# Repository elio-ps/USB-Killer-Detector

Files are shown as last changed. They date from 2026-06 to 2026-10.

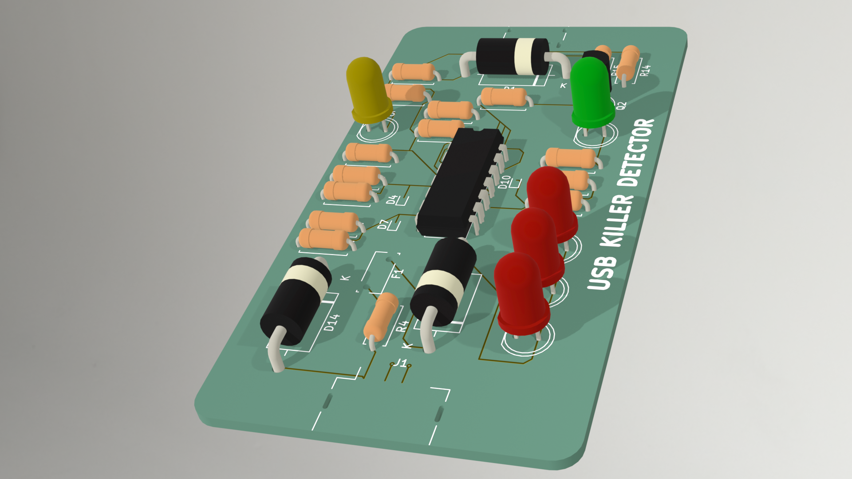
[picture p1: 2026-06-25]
PCB/rednue.png

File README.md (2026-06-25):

# USB Killer Detector

> An open-source tool for detecting, monitoring, and analyzing potentially dangerous USB devices before they can harm your system.

## License

This project is licensed under the GNU GPL v3.0.
See the LICENSE file for more information.

## Overview

USB Killer Detector is an open-source security tool designed to help users identify and inspect USB devices connected to their systems. The project aims to improve hardware security awareness and provide useful information about connected peripherals through real-time monitoring and analysis.

## Demo Video

<p align="center">
  Demo
</p>

*Click the image to watch the demonstration video.*

## Features

* Real-time USB device detection
* Device information gathering and analysis
* Event logging and monitoring
* Detection of suspicious USB behaviors
* Lightweight and efficient design
* Open-source and community-driven
* Easy integration into security workflows

## Why This Project?

Malicious USB devices can pose serious risks to computers and embedded systems. USB * Evan Siby
Killer Detector provides visibility into connected hardware, helping users better understand what devices are attached to their systems and identify potentially dangerous behavior.

## Installation

```bash
git clone https://github.com/elio-ps/USB-Killer-Detector.git
cd USB-Killer-Detector
```

## Architecture

The project is built around several core components:

* USB device monitoring
* Device information collection
* Analysis engine
* Event logging system
* User interface and reporting

## Contributing

Contributions are welcome.

1. Fork the repository
2. Create a feature branch
3. Commit your changes
4. Open a Pull Request

## Acknowledgments

Thanks to all contributors, testers, and members of the open-source community who help improve this project :
* Philippe Mege
* Lenny Gaillard
* Evan Siby
* Lucas Rios

## About Us

We are currently beginners in electronics and embedded systems. This project is mainly a learning experience where we explore USB devices, hardware behavior, and basic security concepts.

We’re improving step by step, so any advice, ideas, or contributions are very welcome!

## Support

If you find this project useful, consider giving it a ⭐ on GitHub and sharing your feedback.

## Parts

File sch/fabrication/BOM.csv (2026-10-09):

Repere | Valeur | Empreinte | Reference fabricant | Quantite
C1 | 10uF | Capacitor_SMD:C_0805_2012Metric |  | 1
C2,C3,C4,C8,C9,C10 | 100nF | Capacitor_SMD:C_0805_2012Metric |  | 6
C5,C6,C7 | 1nF | Capacitor_SMD:C_0805_2012Metric |  | 3
C11 | 1uF | Capacitor_SMD:C_0805_2012Metric |  | 1
D1,D4 | SMAJ5.0A | Diode_SMD:D_SMA | SMAJ5.0A | 2
D2 | Orange PWR | LED_THT:LED_D5.0mm |  | 1
D3 | SS34 | Diode_SMD:D_SMA | SS34 | 1
D5,D6,D7 | BAT54S | Package_TO_SOT_SMD:SOT-23 | BAT54S | 3
D8,D12,D13,D14 | 1N4148W | Diode_SMD:D_SOD-123 | 1N4148W | 4
D9 | Rouge D+ | LED_THT:LED_D5.0mm |  | 1
D10 | Rouge D- | LED_THT:LED_D5.0mm |  | 1
D11 | Rouge VBUS | LED_THT:LED_D5.0mm |  | 1
D15 | Verte OK | LED_THT:LED_D5.0mm |  | 1
F1 | 500mA hold | Fuse:Fuse_1812_4532Metric | Bourns MF-MSMF050-2 | 1
J1 | USB-A test | Connector_USB:USB_A_Receptacle_GCT_USB1046 | GCT USB1046 | 1
J2 | USB-C alim | Connector_USB:USB_C_Receptacle_GCT_USB4125-xx-x_6P_TopMnt_Horizontal | GCT USB4125-GF-A | 1
R1,R2 | 5.1k | Resistor_SMD:R_0805_2012Metric |  | 2
R3,R22,R23,R24,R26 | 1k | Resistor_SMD:R_0805_2012Metric |  | 5
R4 | 51k | Resistor_SMD:R_0805_2012Metric |  | 1
R5 | 33k | Resistor_SMD:R_0805_2012Metric |  | 1
R6 | 15k | Resistor_SMD:R_0805_2012Metric |  | 1
R7,R8,R11,R12 | 220k | Resistor_SMD:R_1206_3216Metric |  | 4
R9,R13 | 220k | Resistor_SMD:R_0805_2012Metric |  | 2
R10,R14 | 120k | Resistor_SMD:R_0805_2012Metric |  | 2
R15 | 100k | Resistor_SMD:R_1206_3216Metric |  | 1
R16 | 150k | Resistor_SMD:R_0805_2012Metric |  | 1
R17 | 43k | Resistor_SMD:R_0805_2012Metric |  | 1
R18,R19,R20 | 10k | Resistor_SMD:R_0805_2012Metric |  | 3
R21,R25 | 100k | Resistor_SMD:R_0805_2012Metric |  | 2
SW1 | RESET | Button_Switch_SMD:SW_SPST_B3S-1000 | Omron B3S-1000 | 1
U1,U2 | LM339 | Package_SO:SOIC-14_3.9x8.7mm_P1.27mm | LM339DR | 2
U3 | 74HC279 | Package_SO:SOIC-16_3.9x9.9mm_P1.27mm | 74HC279D | 1

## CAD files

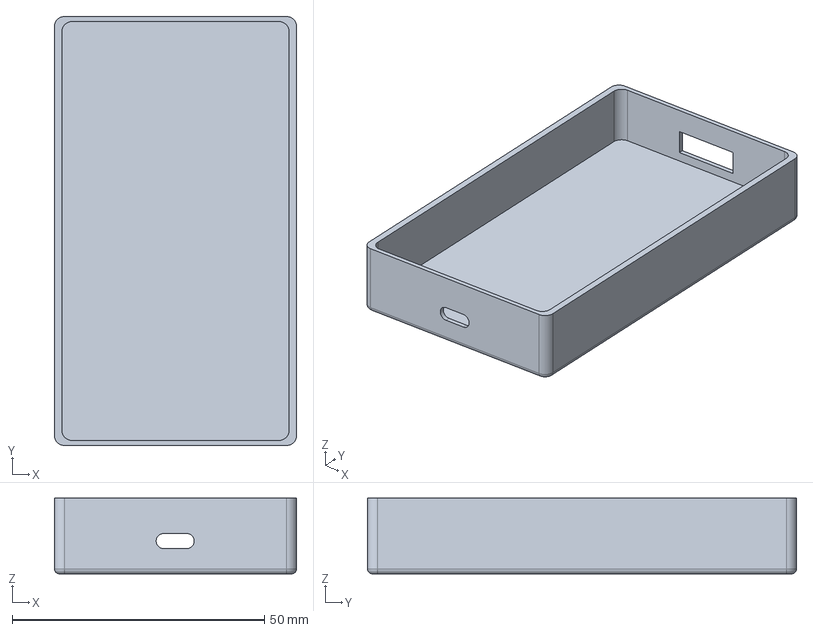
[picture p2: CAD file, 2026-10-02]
PCB/Case/Case.FCStd
48.0 x 85.0 x 15.0 mm

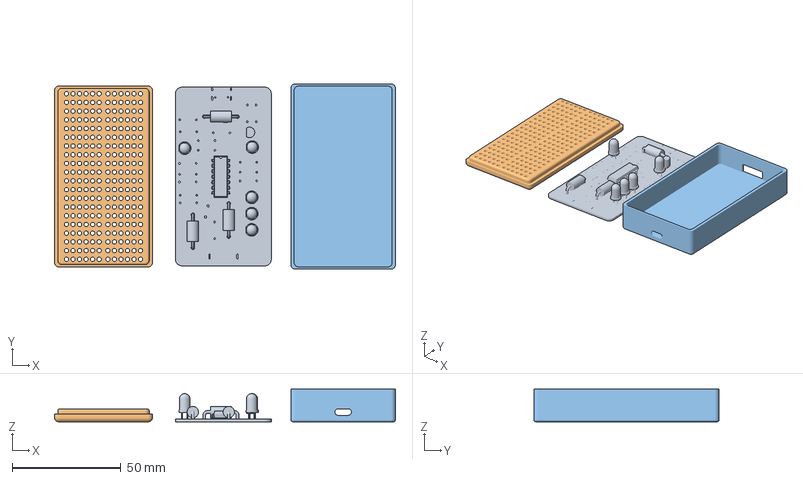
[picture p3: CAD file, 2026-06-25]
PCB/Model.3mf
156.5 x 85.0 x 15.0 mm
a
couvercle-Body
boitier-Body

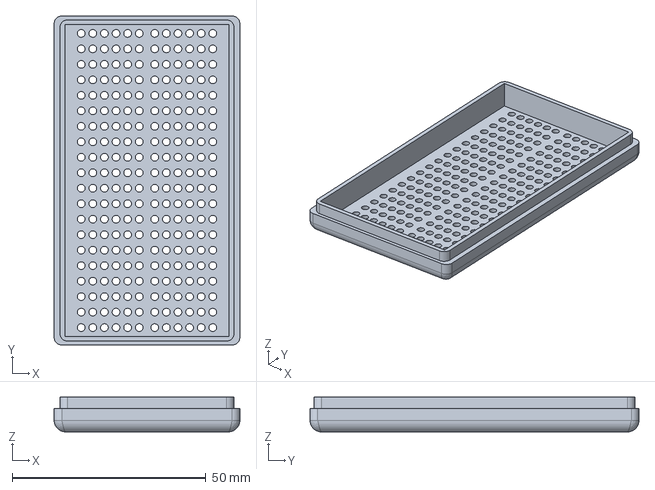
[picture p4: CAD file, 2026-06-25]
PCB/Case/Lid.FCStd
48.0 x 85.0 x 9.00 mm

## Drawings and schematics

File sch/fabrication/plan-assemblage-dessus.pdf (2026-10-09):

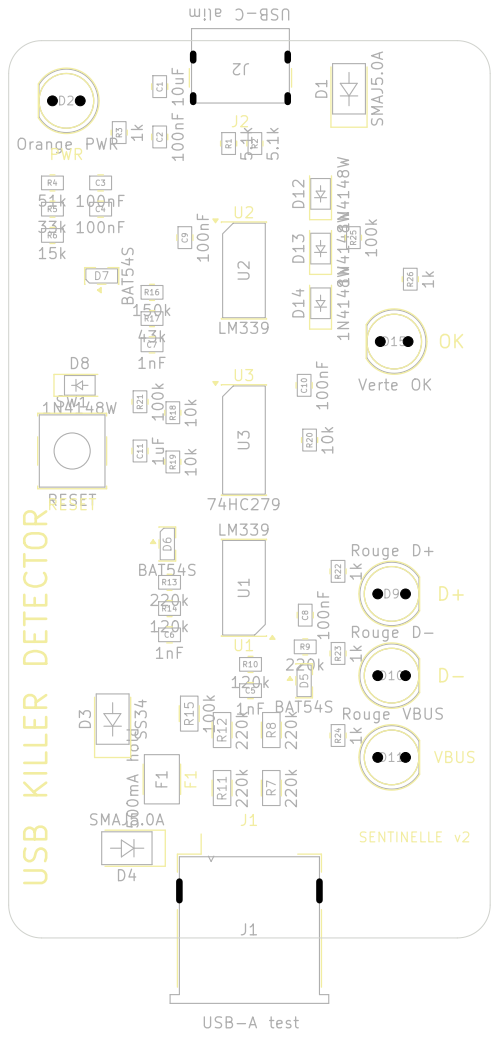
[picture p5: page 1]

File: usb-killer-detector.kicad_pcb
Title:

Size: A4 | Rev:
KiCad E.D.A. 10.0.3 | Id: 1/1

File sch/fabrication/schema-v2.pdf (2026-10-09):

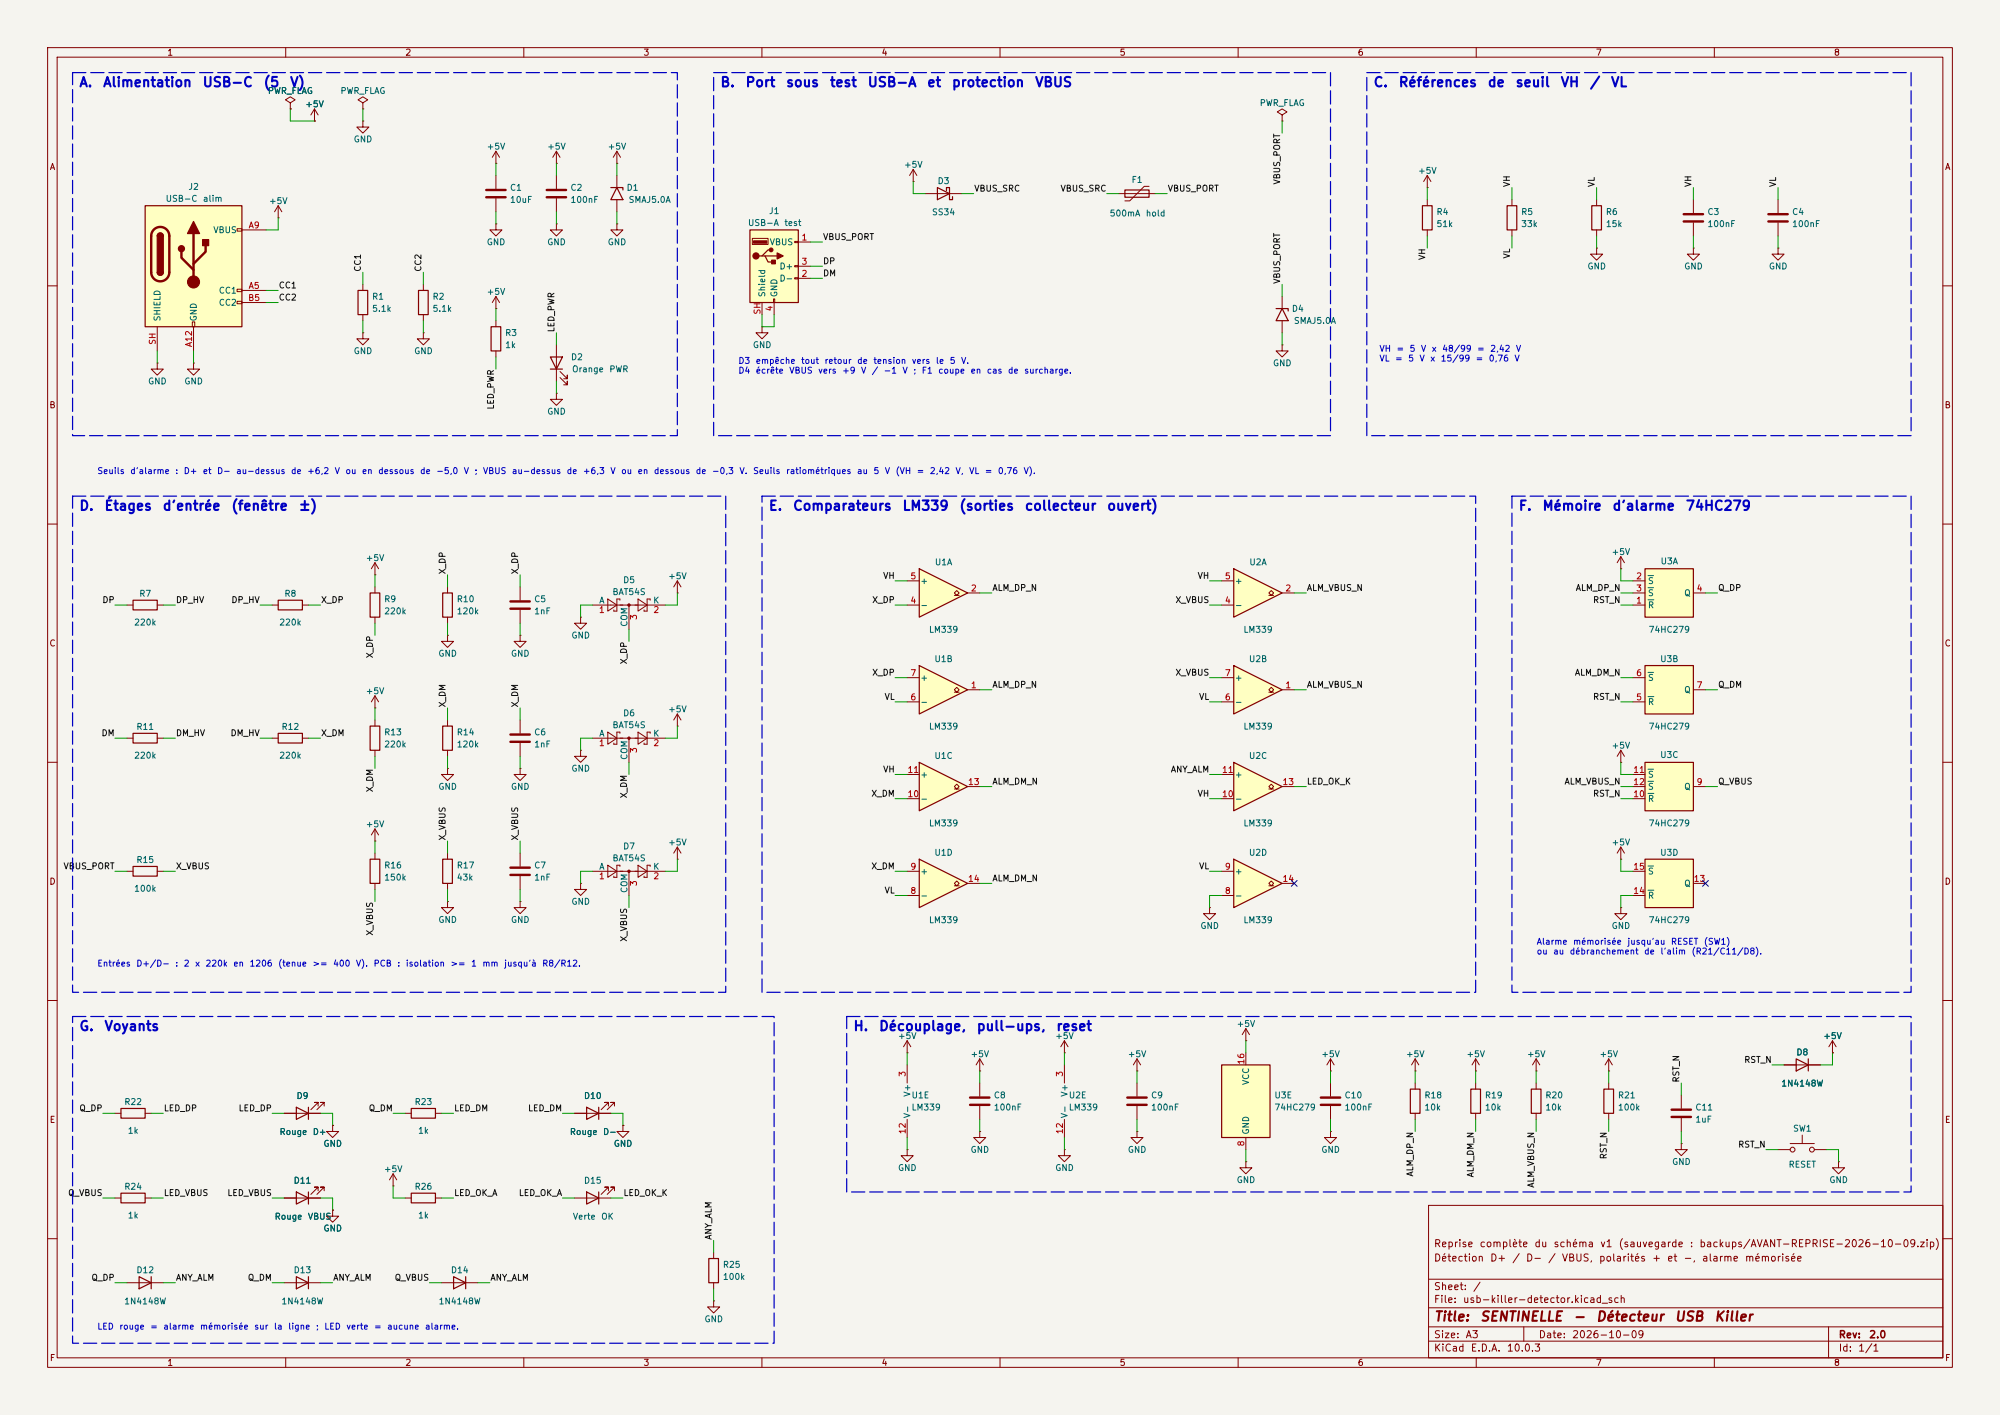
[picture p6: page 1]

VL = 5 V x 15/99 = 0,76 V C. Références de seuil VH / VL

D3 empêche tout retour de tension vers le 5 V. D4 écrête VBUS vers +9 V / -1 V ; F1 coupe en cas de surcharge.

LED rouge = alarme mémorisée sur la ligne ; LED verte = aucune alarme. Entrées D+/D- : 2 x 220k en 1206 (tenue >= 400 V). PCB : isolation >= 1 mm jusqu'à R8/R12.

H. Découplage, pull-ups, reset

Reprise complète du schéma v1 (sauvegarde : backups/AVANT-REPRISE-2026-10-09.zip)
Détection D+ / D- / VBUS, polarités + et -, alarme mémorisée

Sheet: /
File: usb-killer-detector.kicad_sch
Title: SENTINELLE - Détecteur USB Killer

Size: A3 | Rev: 2.0
KiCad E.D.A. 10.0.3 | Id: 1/1 | F Date: 2026-10-09

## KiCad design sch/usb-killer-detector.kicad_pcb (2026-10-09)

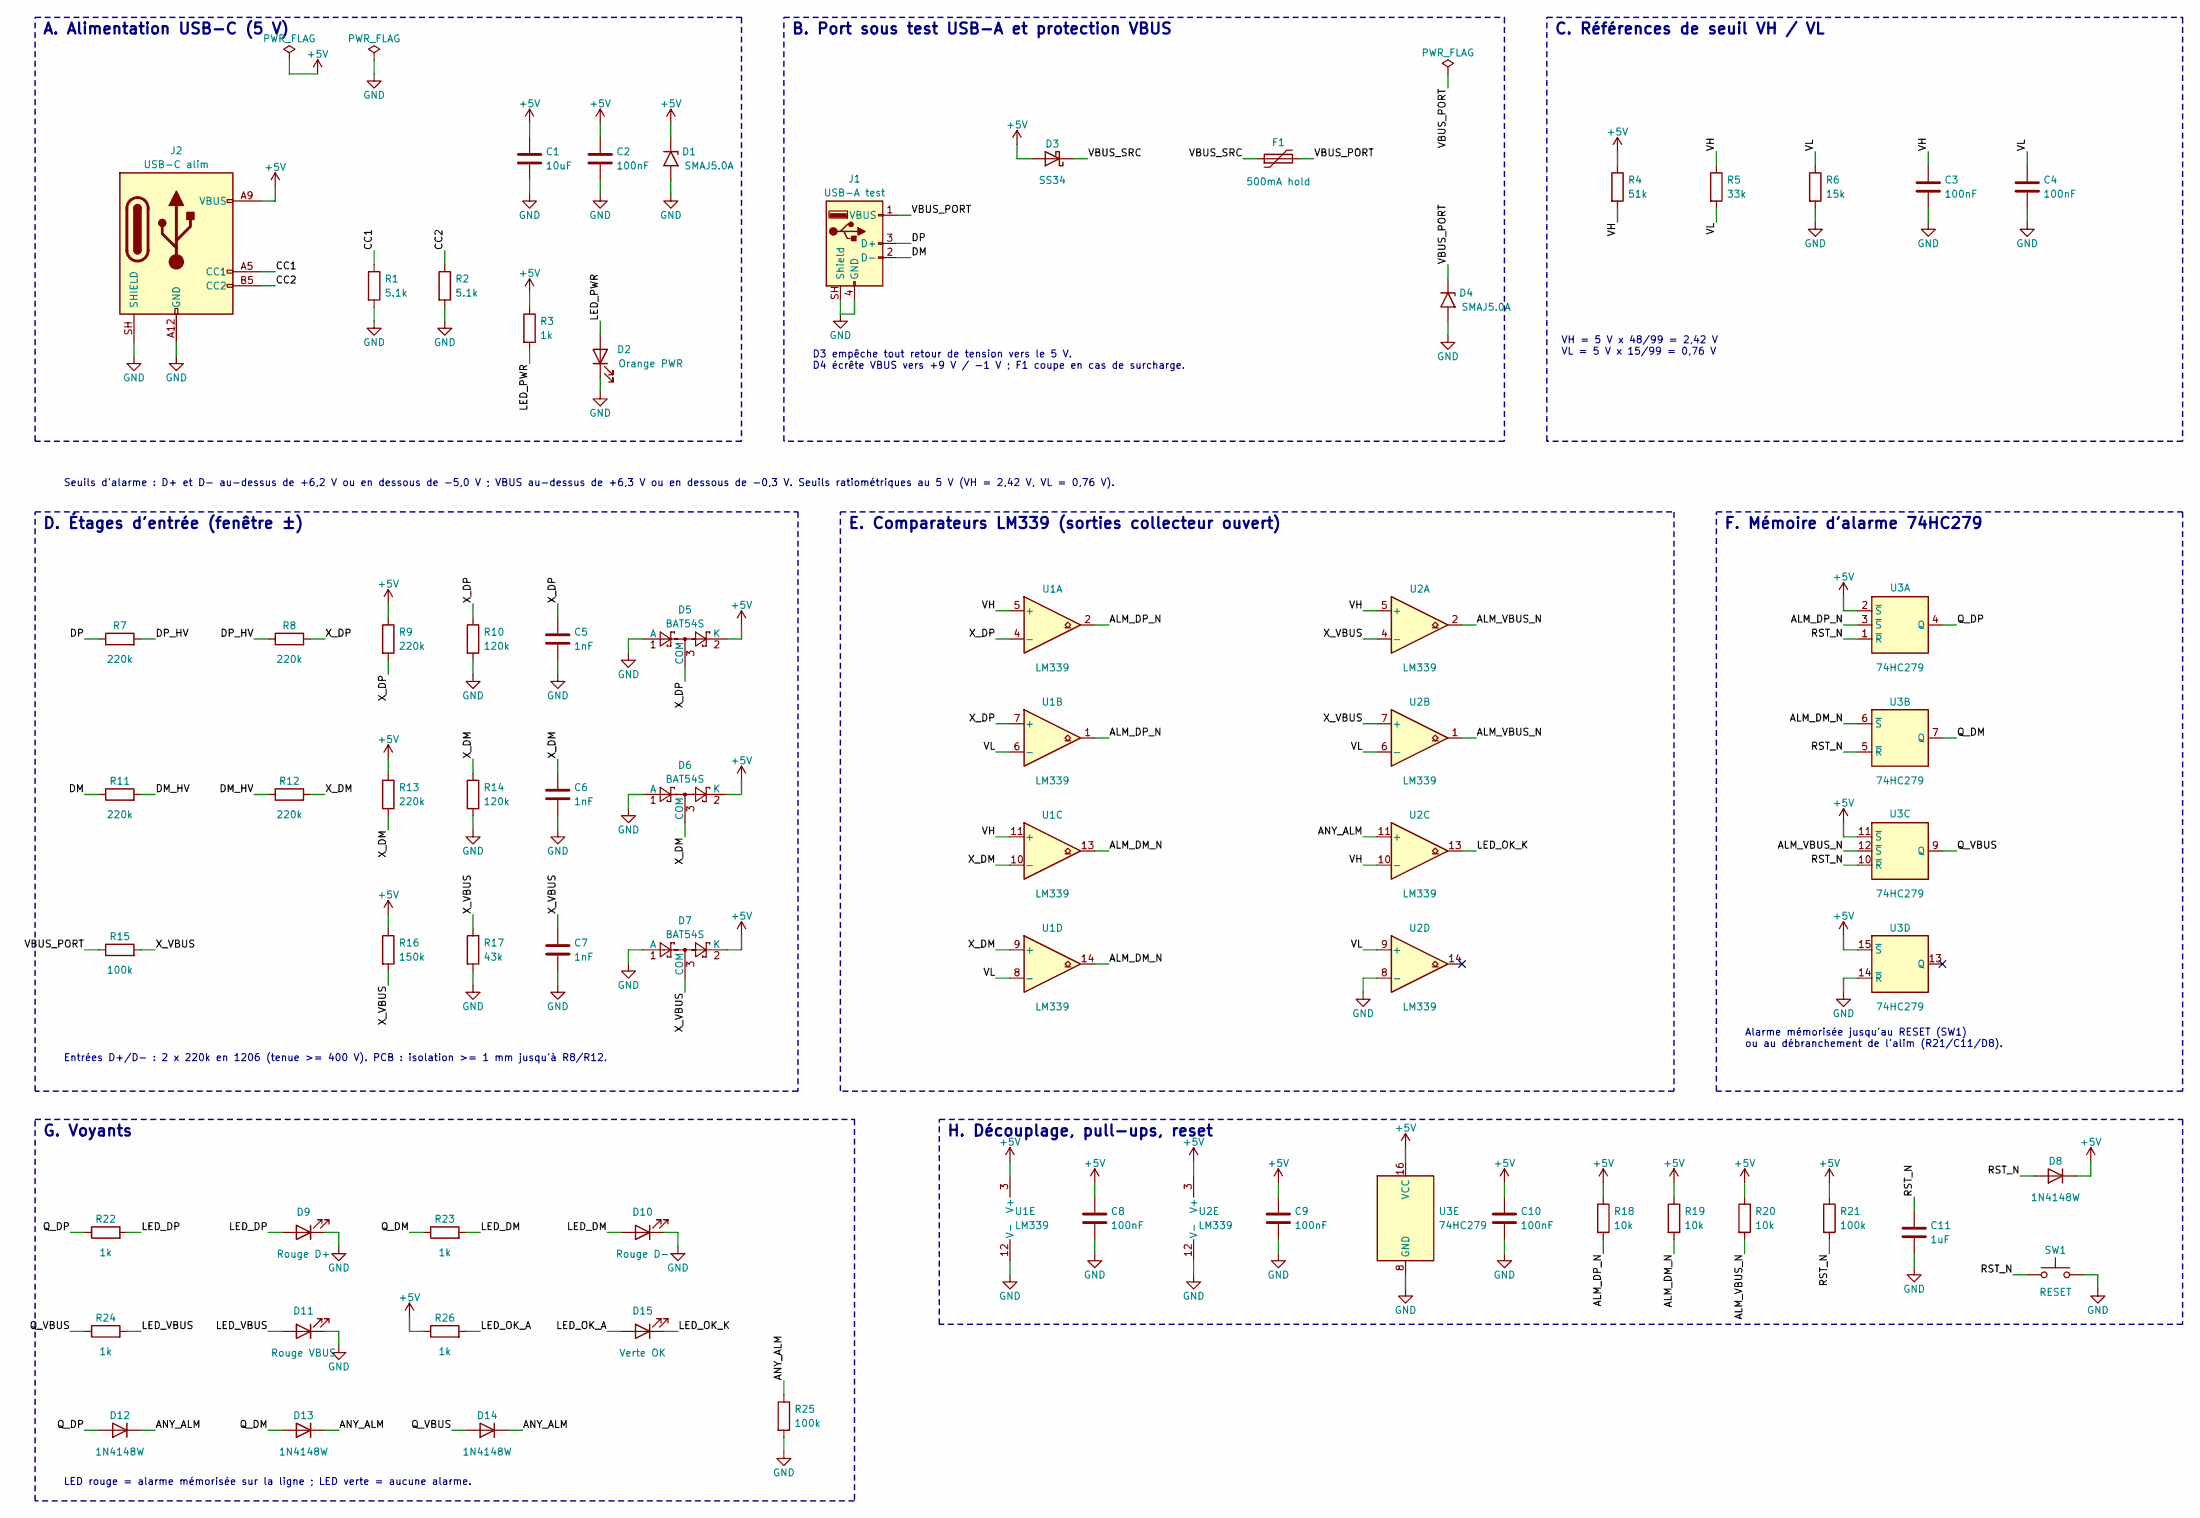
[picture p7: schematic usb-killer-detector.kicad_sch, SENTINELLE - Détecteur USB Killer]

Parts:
C1: 10uF; C_0805_2012Metric
C2, C3, C4, C8, C9, C10: 100nF; C_0805_2012Metric
C5, C6, C7: 1nF; C_0805_2012Metric
C11: 1uF; C_0805_2012Metric
D1, D4: SMAJ5.0A; D_SMA; MPN SMAJ5.0A
D2: Orange PWR; LED_D5.0mm
D3: SS34; D_SMA; MPN SS34
D5, D6, D7: BAT54S; SOT-23; MPN BAT54S
D8, D12, D13, D14: 1N4148W; D_SOD-123; MPN 1N4148W
D9: Rouge D+; LED_D5.0mm
D10: Rouge D-; LED_D5.0mm
D11: Rouge VBUS; LED_D5.0mm
D15: Verte OK; LED_D5.0mm
F1: 500mA hold; Fuse_1812_4532Metric; MPN Bourns MF-MSMF050-2
J1: USB-A test; USB_A_Receptacle_GCT_USB1046; MPN GCT USB1046
J2: USB-C alim; USB_C_Receptacle_GCT_USB4125-xx-x_6P_TopMnt_Horizontal; MPN GCT USB4125-GF-A
R1, R2: 5.1k; R_0805_2012Metric
R3, R22, R23, R24, R26: 1k; R_0805_2012Metric
R4: 51k; R_0805_2012Metric
R5: 33k; R_0805_2012Metric
R6: 15k; R_0805_2012Metric
R7, R8, R11, R12: 220k; R_1206_3216Metric
R9, R13: 220k; R_0805_2012Metric
R10, R14: 120k; R_0805_2012Metric
R15: 100k; R_1206_3216Metric
R16: 150k; R_0805_2012Metric
R17: 43k; R_0805_2012Metric
R18, R19, R20: 10k; R_0805_2012Metric
R21, R25: 100k; R_0805_2012Metric
SW1: RESET; SW_SPST_B3S-1000; MPN Omron B3S-1000
U1, U2: LM339; SOIC-14_3.9x8.7mm_P1.27mm; MPN LM339DR
U3: 74HC279; SOIC-16_3.9x9.9mm_P1.27mm; MPN 74HC279D

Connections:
+5V: C1.1, C2.1, C8.1, C9.1, C10.1, D1.1 (A1), D3.2 (A), D5.2 (K), D6.2 (K), D7.2 (K), D8.1 (K), J2.A9 (VBUS), J2.B9 (VBUS), R3.1, R4.1, R9.1, R13.1, R16.1, R18.1, R19.1, R20.1, R21.1, R26.1, U1.3 (V+), U2.3 (V+), U3.2 (~S), U3.11 (~S), U3.15 (~S), U3.16 (VCC)
/ALM_DM_N: R19.2, U1.13, U1.14, U3.6 (~S)
/ALM_DP_N: R18.2, U1.1, U1.2, U3.3 (~S)
/ALM_VBUS_N: R20.2, U2.1, U2.2, U3.12 (~S)
/ANY_ALM: D12.1 (K), D13.1 (K), D14.1 (K), R25.1, U2.11 (+)
/CC1: J2.A5 (CC1), R1.1
/CC2: J2.B5 (CC2), R2.1
/DM: J1.2 (D-), R11.1
/DM_HV: R11.2, R12.1
/DP: J1.3 (D+), R7.1
/DP_HV: R7.2, R8.1
/LED_DM: D10.2 (A), R23.2
/LED_DP: D9.2 (A), R22.2
/LED_OK_A: D15.2 (A), R26.2
/LED_OK_K: D15.1 (K), U2.13
/LED_PWR: D2.2 (A), R3.2
/LED_VBUS: D11.2 (A), R24.2
/Q_DM: D13.2 (A), R23.1, U3.7 (Q)
/Q_DP: D12.2 (A), R22.1, U3.4 (Q)
/Q_VBUS: D14.2 (A), R24.1, U3.9 (Q)
/RST_N: C11.1, D8.2 (A), R21.2, SW1.1, U3.1 (~R), U3.5 (~R), U3.10 (~R)
/VBUS_PORT: D4.1 (A1), F1.2, J1.1 (VBUS), R15.1
/VBUS_SRC: D3.1 (K), F1.1
/VH: C3.1, R4.2, R5.1, U1.5 (+), U1.11 (+), U2.5 (+), U2.10 (-)
/VL: C4.1, R5.2, R6.1, U1.6 (-), U1.8 (-), U2.6 (-), U2.9 (+)
/X_DM: C6.1, D6.3 (COM), R12.2, R13.2, R14.1, U1.9 (+), U1.10 (-)
/X_DP: C5.1, D5.3 (COM), R8.2, R9.2, R10.1, U1.4 (-), U1.7 (+)
/X_VBUS: C7.1, D7.3 (COM), R15.2, R16.2, R17.1, U2.4 (-), U2.7 (+)
GND: C1.2, C2.2, C3.2, C4.2, C5.2, C6.2, C7.2, C8.2, C9.2, C10.2, C11.2, D1.2 (A2), D2.1 (K), D4.2 (A2), D5.1 (A), D6.1 (A), D7.1 (A), D9.1 (K), D10.1 (K), D11.1 (K), J1.4 (GND), J1.SH (Shield), J2.A12 (GND), J2.B12 (GND), J2.SH (SHIELD), R1.2, R2.2, R6.2, R10.2, R14.2, R17.2, R25.2, SW1.2, U1.12 (V-), U2.8 (-), U2.12 (V-), U3.8 (GND), U3.14 (~R)

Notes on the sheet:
A. Alimentation USB-C (5 V)
B. Port sous test USB-A et protection VBUS
C. Références de seuil VH / VL
D. Étages d'entrée (fenêtre ±)
E. Comparateurs LM339 (sorties collecteur ouvert)
F. Mémoire d'alarme 74HC279
G. Voyants
H. Découplage, pull-ups, reset
Seuils d'alarme : D+ et D- au-dessus de +6,2 V ou en dessous de -5,0 V ; VBUS au-dessus de +6,3 V ou en dessous de -0,3 V. Seuils ratiométriques au 5 V (VH = 2,42 V, VL = 0,76 V).
VH = 5 V x 48/99 = 2,42 V VL = 5 V x 15/99 = 0,76 V
D3 empêche tout retour de tension vers le 5 V. D4 écrête VBUS vers +9 V / -1 V ; F1 coupe en cas de surcharge.
Entrées D+/D- : 2 x 220k en 1206 (tenue >= 400 V). PCB : isolation >= 1 mm jusqu'à R8/R12.
Alarme mémorisée jusqu'au RESET (SW1) ou au débranchement de l'alim (R21/C11/D8).
LED rouge = alarme mémorisée sur la ligne ; LED verte = aucune alarme.

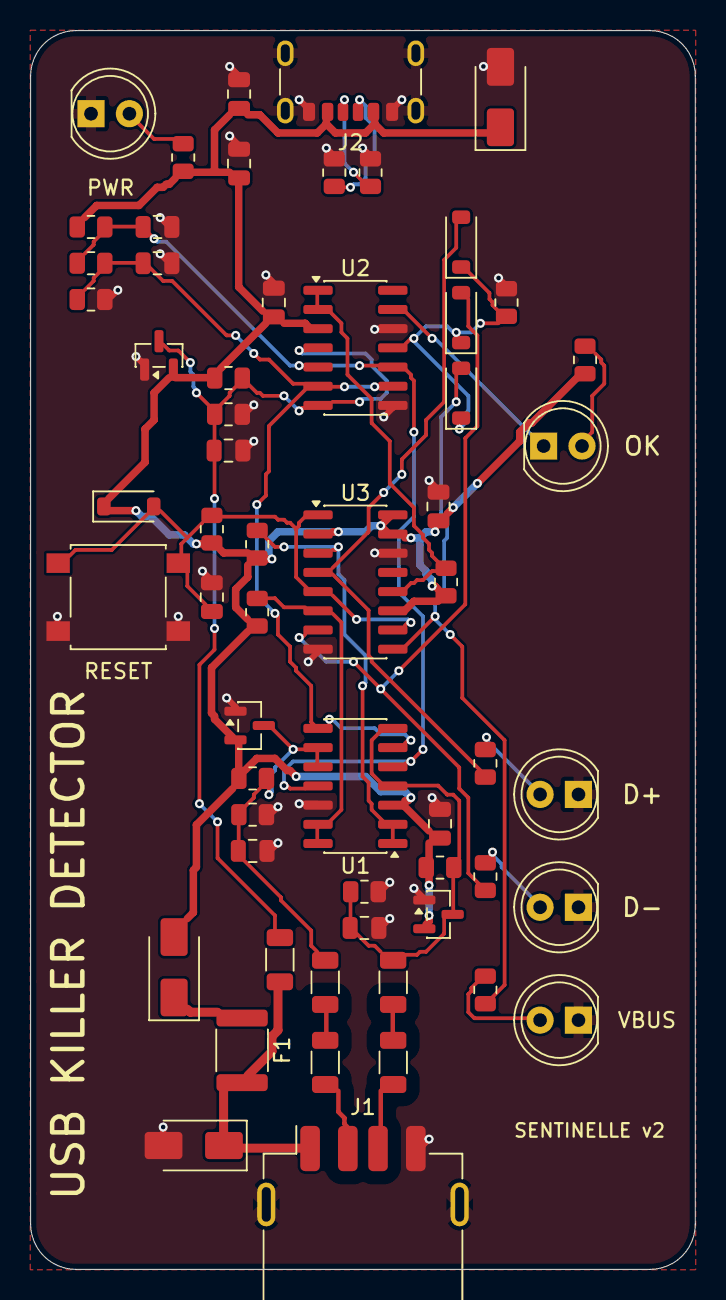
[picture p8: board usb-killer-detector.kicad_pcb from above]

Board: 2 copper layers, 44.0 x 82.0 mm, 59 parts (0 on the bottom side), 29 nets.

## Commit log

2026-06-25 PCB: GND
    [usb-killer-detector.kicad_pcb]
2026-10-02 Fix: 3D Case
    [Case.FCStd]
2026-10-09 Reprise v2 : schéma refait, PCB routé et dossier de fabrication
    - Détection des deux polarités sur D+, D- et VBUS : comparateurs à
    fenêtre (2x LM339), seuils D+/D- +6,2 V / -5,0 V, VBUS +6,3 V / -0,3 V
    - Alerte mémorisée (74HC279) avec bouton RESET et reset à la mise
    sous tension ; LED verte « OK » quand aucune alerte
    - Protections : TVS SMAJ5.0A, clamps BAT54S, diode anti-retour SS34,
    polyfuse 500 mA
    - PCB 44 x 82 mm entièrement routé, plans de masse sur les deux faces
    - Règles d'isolation des lignes haute tension (kicad_dru) et classes
    de pistes (Power, HV)
    - ERC 0, DRC 0 : les 2 avertissements de sérigraphie du connecteur
    USB-A (corps hors carte par construction)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
    [BOM.csv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]
2026-10-29 Rapports ERC et DRC (kicad-cli 10.0.3)
    ERC : 0 erreur, 0 avertissement.
    DRC (avec parité schéma) : 0 violation, 0 pad non connecté, 0 écart
    de parité ; seuls restent les 2 avertissements de sérigraphie de J1
    déjà exclus et justifiés dans le .kicad_pro.
    Vérifié aussi sans rien modifier : zones de cuivre à jour (recalcul
    identique) et gerbers/perçages régénérés identiques à ceux du dépôt,
    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
2026-10-29 Boîtier : vérification contre le PCB v2 et macro de correction
    Export du modèle 3D du PCB v2 (PCB/SENTINELLE-v2-PCB.step, kicad-cli,
    sans J1 ni F1 faute de modèle dans la bibliothèque KiCad 10).
    Vérification par calcul (cotes KiCad, esquisses des .FCStd, plans GCT),
    détaillée dans docs/boitier-v2.md :
    - USB-A : fenêtre 14 x 5 mm trop basse pour l'USB1046 (7,12 mm) et
    collerette de 14,5 mm impossible à passer -> fente en U ;
    - USB-C : fente décalée de 0,88 mm et trop étroite -> ouverture recentrée ;
    - 5 LED et RESET sans aucun trou -> trous + tubes guides dans le couvercle ;
    - broches traversantes sous le PCB -> dégagements dans le fond.
    La macro PCB/Case/maj_boitier_v2.FCM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
2026-10-29 BOM JLCPCB : références LCSC vérifiées et CPL au format JLC
    Les fichiers JLC préparés à la main n'étaient pas sur ce poste : la BOM
    est reconstruite depuis BOM.csv (59 composants, 30 lignes), chaque
    numéro LCSC étant vérifié sur le catalogue JLCPCB le 29/10/2026
    (existence, stock, boîtier). Les 5 LED restent en soudure main (lignes
    jaunes, sans numéro).
    - R7/R8/R11/R12 : 220k 1206 1 % YAGEO RV1206 500 V (C873512) au lieu de
    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
2026-10-29 Ne plus suivre les sauvegardes KiCad et FreeCAD
    Ajout de *-backups/ et *.FCBak au .gitignore et retrait du suivi
    (git rm --cached) des 71 zips de sch/usb-killer-detector-backups/ et
    des 2 .FCBak de PCB/Case/. Les fichiers restent sur le disque ; leur
    contenu reste accessible dans l'historique git.
2026-10-29 README : décrire le détecteur matériel SENTINELLE v2
    L'ancien README présentait un logiciel de surveillance USB. Il décrit
    maintenant la carte : utilisation, fonctionnement par blocs A à H du
    schéma, seuils (D+/D- > +6,2 V ou < -5 V, VBUS > +6,3 V ou < -0,3 V),
    voyants, reset, contenu de sch/fabrication/ (fichiers à téléverser chez
    JLCPCB), boîtier, sécurité, équipe complète et remerciement.
    demo.gif (prototype breadboard v1, 30 Mo) n'est plus affiché en grand :
    simple lien, plus un TODO pour une démo de la v2.
2026-10-29 Protocole de test sans USB Killer (docs/protocole-test.md)
    Validation à l'alimentation de labo avec résistance série, règles de
    sécurité en tête : surtension et tension négative sur D+, D- (10 kOhm)
    et VBUS (22 Ohm), LED attendue, mémorisation, RESET et coupure
    d'alimentation, tableau seuils théoriques / fourchette ±1 % / mesurés.
    VBUS négatif : la carte maintient elle-même VBUS à +4,6 V, donc l'essai
    se fait par décharge d'un condensateur non polarisé chargé à 5 V
    (méthode calculée, pas encore essayée).
2026-10-29 Macro boîtier : trouver Case.FCStd même lancée hors de PCB/Case
    Lancée par freecadcmd depuis la racine du dépôt, __file__ peut manquer :
    la macro cherche maintenant dans son dossier, le dossier courant puis
    PCB/Case.
2026-10-29 Boîtier mis à jour pour le PCB v2 (macro exécutée)
    maj_boitier_v2.FCMacro lancée sous FreeCAD 1.1.4 (freecadcmd) :
    - Case.FCStd : 11 fonctions V2 (fente USB-A en U, ouverture USB-C
    recentrée, dégagements sous les broches traversantes) ;
    - Lid.FCStd : 13 fonctions V2 (encoche de lèvre, 5 tubes et trous de
    LED, tube et trou RESET), 34 trous d'aération retirés ;
    - contrôle avec le STEP du PCB v2 : 75 pièces, 0 interférence ;
    - Model.3mf régénéré (boîtier + couvercle à 60 mm).
    Model.3mf vérifié par calcul : maillages fermés, 22 points de contrôle
    (matière ou vide) conformes. README et docs/boitier-v2.md à jour.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
2026-10-29 BOM : les 5 LED sont aussi assemblées par JLC
    L'équipe n'a pas de quoi souder : plus aucune ligne en soudure main.
    LED 5 mm traversantes, numéros vérifiés chez JLC et datasheets lues
    (Ø 5 mm, entraxe 2,54 mm, 8,6-8,7 mm de haut) :
    - D2 orange : C52034657 (Guiguang 5A4OUD)
    - D9/D10/D11 rouges : C87271 (Everlight 333-2SURD/S530-A3)
    - D15 verte : C2895548 (Xinglight XL-502UGD, lumineuse à 2 mA)
    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
2026-10-31 Adapter la commande JLC à sch/production (Fabrication Toolkit)
    On garde la structure de f171ace (sch/production/ générée par le plugin
    Fabrication Toolkit, positions déjà corrigées pour JLC) et on y remet
    les choix vérifiés :
    - champ « LCSC Part # » ajouté aux 59 composants, dans le schéma et le
    PCB, pour que le plugin reprenne les numéros à chaque régénération ;
    - bom.csv : colonne LCSC remplie avec les numéros vérifiés (R7/R8/R11/R12
    à 1 %, LM339DR TI, les 5 LED…) ;
    - ERC 0 et DRC sur le PCB modifié : 2 exclusions déjà justifiées, 0 écart
    de parité, rapports dans sch/rapports/ ;
    - README et docs/bom-jlcpcb.md pointent vers sch/production/, et le .xls
    d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
